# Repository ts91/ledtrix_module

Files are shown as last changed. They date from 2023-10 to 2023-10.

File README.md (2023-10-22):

# Ledtrix, a fully modular 16x16 LED matrix

Tileable and low profile (less than 1cm) for display applications. Can be used in an artsy clock. Each single LED is source/sink driven by a pair of transistors.

The transistors are controlled by shift-registers. There are 4 daisy-chained shift-registers with each 8 outputs giving the required 16 rows and 16 columns drive signals.

## Tileable
The outline of the unit is the same as 4 LED modules in a 2x2 configuration. This makes it possible to seamlessly tile the Ledtrix along any of its four edges.

Signals travel through the board from the left to the right indicated by the arrow and socket. The boards are soldered together by edge connectors. Soldering all of these gives a sturdy unit.

### Mounting holes
There are four mount holes on the back. It is impossible to reach these holes once the LED modules have been soldered onto the PCB. They can be used with press fit mount stages.

## Driving the Ledtrix
This can be tricky as the focus has been to make the PCB routing as simple as possible. Some thought must be put into it.
## Pictures
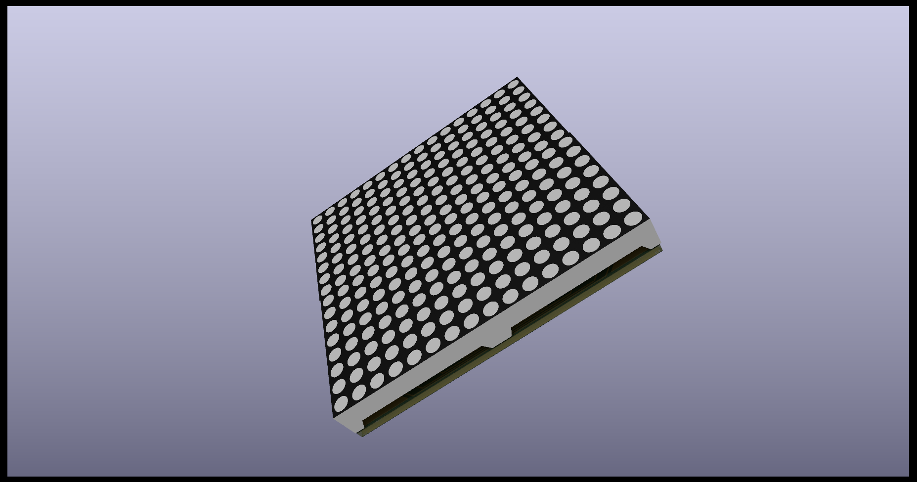
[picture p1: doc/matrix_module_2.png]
Ledtrix, front Front view - with 8x8 LEDs mounted

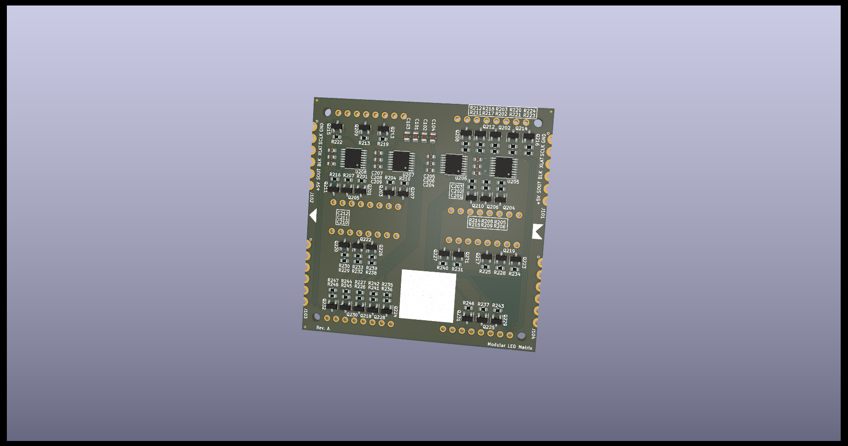
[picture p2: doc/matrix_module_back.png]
Ledtrix, back Back view - SMD component side

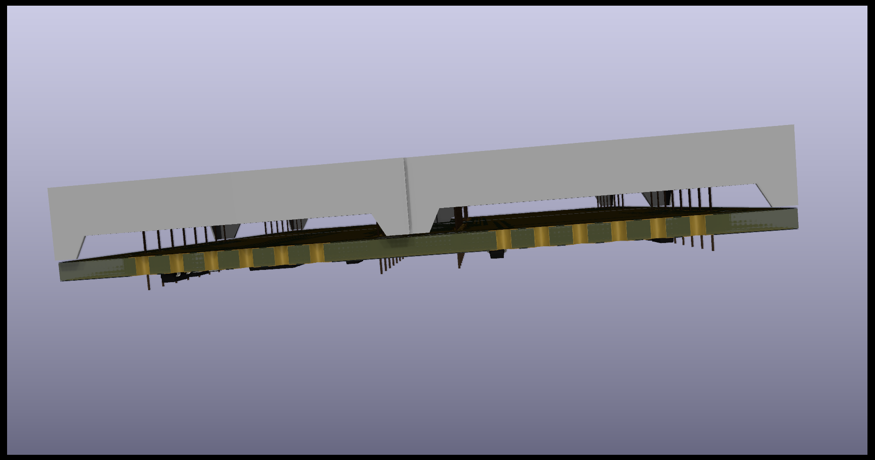
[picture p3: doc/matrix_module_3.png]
Ledtrix, side Side view - profile <1cm thickness

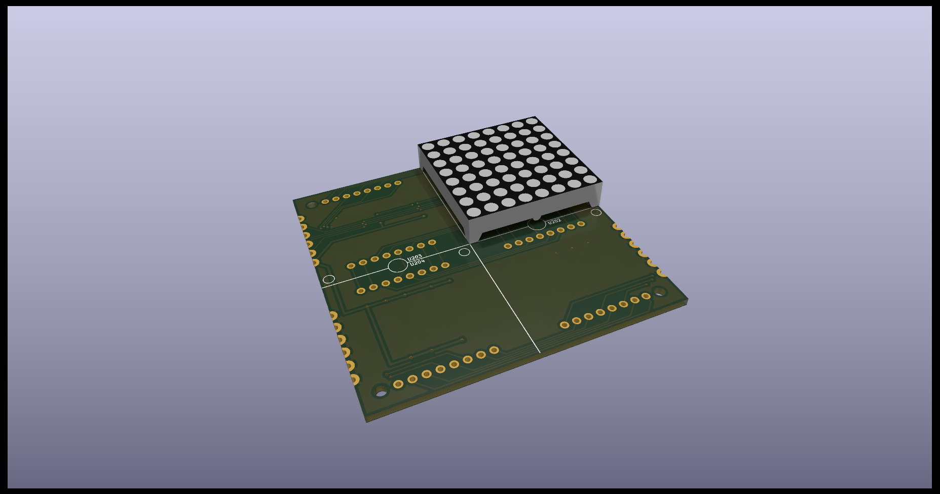
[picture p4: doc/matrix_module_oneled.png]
Ledtrix, front w. one LED Front view - one LED module mounted


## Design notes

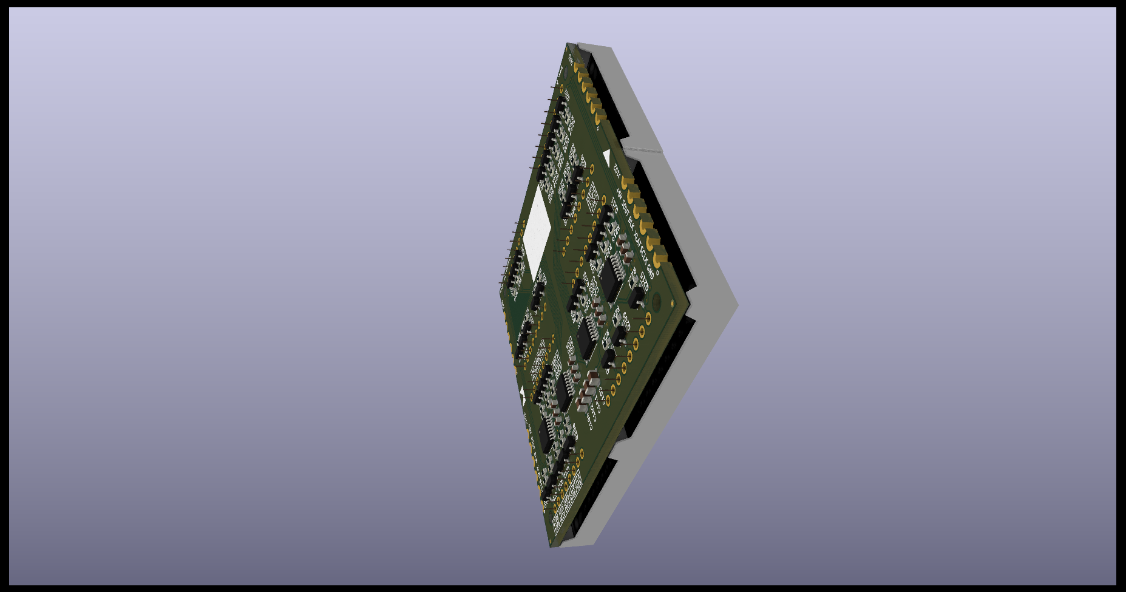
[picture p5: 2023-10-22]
doc/matrix_module_1.png

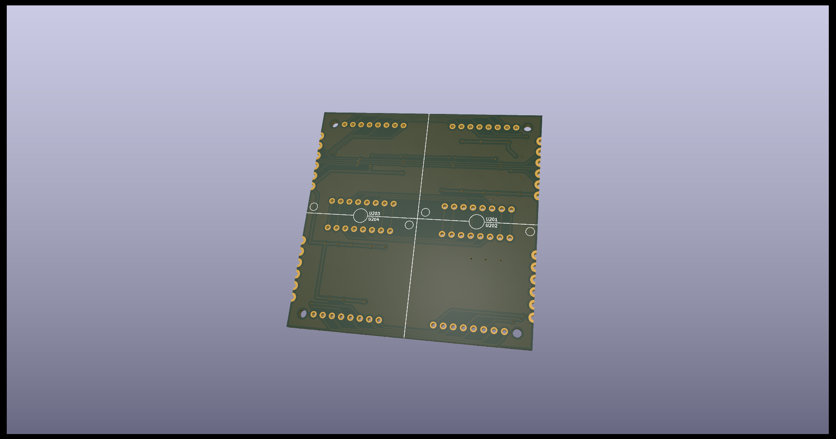
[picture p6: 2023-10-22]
doc/matrix_module_noleds.png

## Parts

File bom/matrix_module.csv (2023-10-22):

Comment | Designator | Footprint | LCSC
10u | C101,C102,C103,C104 | Capacitor_SMD:C_0805_2012Metric
100n | C201,C202,C203,C204,C205,C206,C207,C208,C209,C210,C211,C212 | Capacitor_SMD:C_0603_1608Metric
Fiducial | FID101,FID102,FID103 | Fiducials:Fiducial_0.5mm_Dia_1mm_Outer
MountingHole | H101,H102,H103,H104 | MountingHole:MountingHole_2.2mm_M2
Conn_01x06_Male | J101 | thms:CastellatedEdge_1x06P3.175mm_Vertical
Conn_01x06_Female | J102,J103,J104 | thms:CastellatedEdge_1x06P3.175mm_Vertical
BC807 | Q201,Q203,Q205,Q207,Q209,Q211,Q213,Q215,Q217,Q219,Q221,Q223,Q225,Q227,Q229,Q231 | Package_TO_SOT_SMD:SOT-23
BC817 | Q202,Q204,Q206,Q208,Q210,Q212,Q214,Q216,Q218,Q220,Q222,Q224,Q226,Q228,Q230,Q232 | Package_TO_SOT_SMD:SOT-23
1k | R201,R202,R204,R205,R207,R208,R210,R211,R213,R214,R216,R217,R219,R220,R222,R223,R225,R226,R228,R229,R231,R232,R234,R235,R237,R238,R240,R241,R243,R244,R246,R247 | Resistor_SMD:R_0603_1608Metric
500 | R203,R206,R209,R212,R215,R218,R221,R224,R227,R230,R233,R236,R239,R242,R245,R248 | Resistor_SMD:R_0603_1608Metric
1088BS | U201,U202,U203,U204 | thms:8x8_dotmatrix_1088_Pin_Header
74HC595 | U205,U206,U207,U208 | Package_SO:TSSOP-16_4.4x5mm_P0.65mm | C5948

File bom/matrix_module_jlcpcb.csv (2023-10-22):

Comment | Designator | Footprint | LCSC
10u | C101,C102,C103,C104 | 0805 | C440198
100n | C201,C202,C203,C204,C205,C206,C207,C208,C209,C210,C211,C212 | 0603 | C14663
BC807 | Q201,Q203,Q205,Q207,Q209,Q211,Q213,Q215,Q217,Q219,Q221,Q223,Q225,Q227,Q229,Q231 | SOT-23 | C2926191
BC817 | Q202,Q204,Q206,Q208,Q210,Q212,Q214,Q216,Q218,Q220,Q222,Q224,Q226,Q228,Q230,Q232 | SOT-23 | C2926190
1k | R201,R202,R204,R205,R207,R208,R210,R211,R213,R214,R216,R217,R219,R220,R222,R223,R225,R226,R228,R229,R231,R232,R234,R235,R237,R238,R240,R241,R243,R244,R246,R247 | 0603 | C21190
500 | R203,R206,R209,R212,R215,R218,R221,R224,R227,R230,R233,R236,R239,R242,R245,R248 | 0603 | C23179
74HC595 | U205,U206,U207,U208 | TSSOP-16_4.4x5mm_P0.65mm | C5948

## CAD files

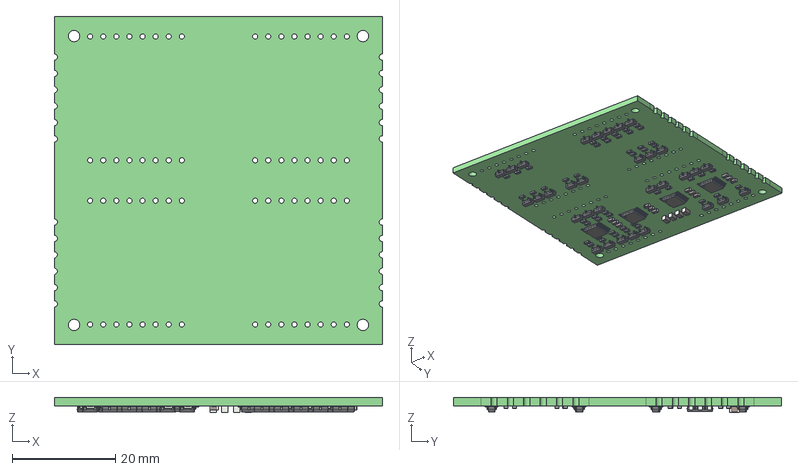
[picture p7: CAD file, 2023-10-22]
matrix_module.step
63.6 x 63.6 x 2.90 mm
matrix_module PCB

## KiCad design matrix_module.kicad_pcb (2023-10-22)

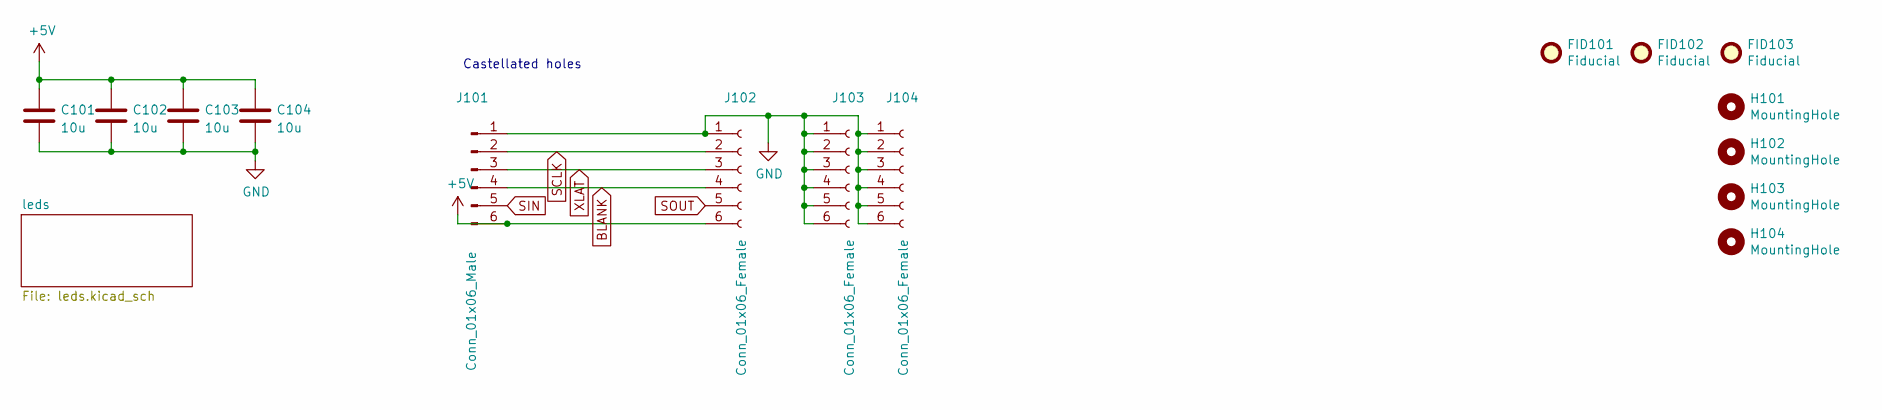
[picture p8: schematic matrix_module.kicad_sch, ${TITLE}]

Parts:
C101, C102, C103, C104: 10u; C_0805_2012Metric
FID101, FID102, FID103: Fiducial; Fiducial_0.5mm_Dia_1mm_Outer
H101, H102, H103, H104: MountingHole; MountingHole_2.2mm_M2
J101: Conn_01x06_Male; CastellatedEdge_1x06P3.175mm_Vertical
J102, J103, J104: Conn_01x06_Female; CastellatedEdge_1x06P3.175mm_Vertical

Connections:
+5V: C101.1, C102.1, C103.1, C104.1, J101.6, J102.6; also elsewhere on the board
BLANK: J101.4, J102.4; also elsewhere on the board
GND: C101.2, C102.2, C103.2, C104.2, J101.1, J102.1, J103.1, J103.2, J103.3, J103.4, J103.5, J103.6, J104.1, J104.2, J104.3, J104.4, J104.5, J104.6; also elsewhere on the board
SCLK: J101.2, J102.2; also elsewhere on the board
SIN: J101.5; also elsewhere on the board
SOUT: J102.5; also elsewhere on the board
XLAT: J101.3, J102.3; also elsewhere on the board

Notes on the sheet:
Castellated holes

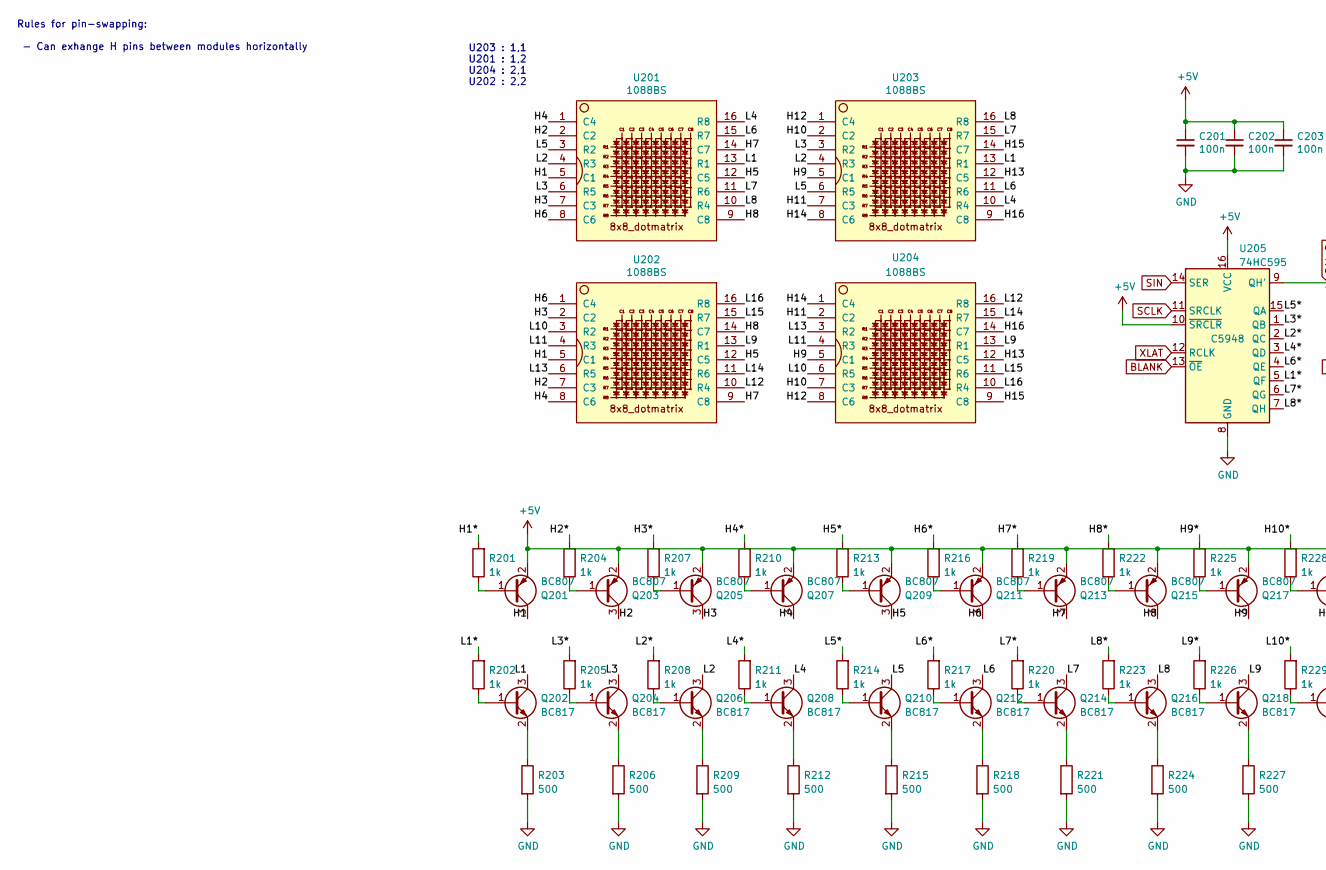
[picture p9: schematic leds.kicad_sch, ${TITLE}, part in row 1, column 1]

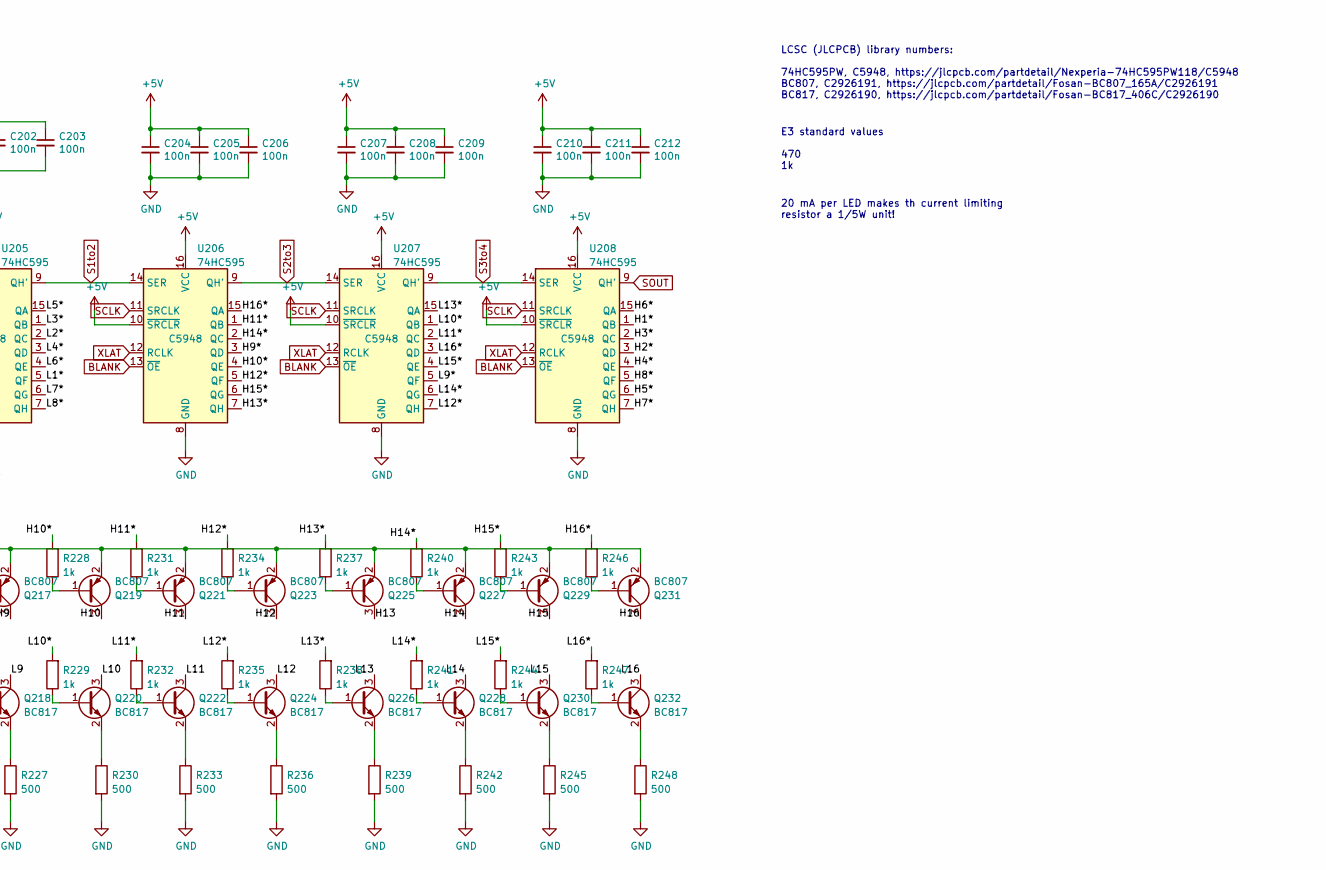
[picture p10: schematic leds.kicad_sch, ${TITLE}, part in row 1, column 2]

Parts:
C201, C202, C203, C204, C205, C206, C207, C208, C209, C210, C211, C212: 100n; C_0603_1608Metric
Q201, Q203, Q205, Q207, Q209, Q211, Q213, Q215, Q217, Q219, Q221, Q223, Q225, Q227, Q229, Q231: BC807; SOT-23
Q202, Q204, Q206, Q208, Q210, Q212, Q214, Q216, Q218, Q220, Q222, Q224, Q226, Q228, Q230, Q232: BC817; SOT-23
R201, R202, R204, R205, R207, R208, R210, R211, R213, R214, R216, R217, R219, R220, R222, R223, R225, R226, R228, R229, R231, R232, R234, R235, R237, R238, R240, R241, R243, R244, R246, R247: 1k; R_0603_1608Metric
R203, R206, R209, R212, R215, R218, R221, R224, R227, R230, R233, R236, R239, R242, R245, R248: 500; R_0603_1608Metric
U201, U202, U203, U204: 1088BS; 8x8_dotmatrix_1088
U205, U206, U207, U208: 74HC595; TSSOP-16_4.4x5mm_P0.65mm; LCSC C5948

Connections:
+5V: C201.1, C202.1, C203.1, C204.1, C205.1, C206.1, C207.1, C208.1, C209.1, C210.1, C211.1, C212.1, Q201.2 (E), Q203.2 (E), Q205.2 (E), Q207.2 (E), Q209.2 (E), Q211.2 (E), Q213.2 (E), Q215.2 (E), Q217.2 (E), Q219.2 (E), Q221.2 (E), Q223.2 (E), Q225.2 (E), Q227.2 (E), Q229.2 (E), Q231.2 (E), U205.10 (~SRCLR), U205.16 (VCC), U206.10 (~SRCLR), U206.16 (VCC), U207.10 (~SRCLR), U207.16 (VCC), U208.10 (~SRCLR), U208.16 (VCC); also elsewhere on the board
/leds/H1: Q201.3 (C), U201.5 (C1), U202.5 (C1)
/leds/H1*: R201.2, U208.1 (QB)
/leds/H2: Q203.3 (C), U201.2 (C2), U202.7 (C3)
/leds/H2*: R204.2, U208.3 (QD)
/leds/H3: Q205.3 (C), U201.7 (C3), U202.2 (C2)
/leds/H3*: R207.2, U208.2 (QC)
/leds/H4: Q207.3 (C), U201.1 (C4), U202.8 (C6)
/leds/H4*: R210.2, U208.4 (QE)
/leds/H5: Q209.3 (C), U201.12 (C5), U202.12 (C5)
/leds/H5*: R213.2, U208.6 (QG)
/leds/H6: Q211.3 (C), U201.8 (C6), U202.1 (C4)
/leds/H6*: R216.2, U208.15 (QA)
/leds/H7: Q213.3 (C), U201.14 (C7), U202.9 (C8)
/leds/H7*: R219.2, U208.7 (QH)
/leds/H8: Q215.3 (C), U201.9 (C8), U202.14 (C7)
/leds/H8*: R222.2, U208.5 (QF)
/leds/H9: Q217.3 (C), U203.5 (C1), U204.5 (C1)
/leds/H9*: R225.2, U206.3 (QD)
/leds/H10: Q219.3 (C), U203.2 (C2), U204.7 (C3)
/leds/H10*: R228.2, U206.4 (QE)
/leds/H11: Q221.3 (C), U203.7 (C3), U204.2 (C2)
/leds/H11*: R231.2, U206.1 (QB)
/leds/H12: Q223.3 (C), U203.1 (C4), U204.8 (C6)
/leds/H12*: R234.2, U206.5 (QF)
/leds/H13: Q225.3 (C), U203.12 (C5), U204.12 (C5)
/leds/H13*: R237.2, U206.7 (QH)
/leds/H14: Q227.3 (C), U203.8 (C6), U204.1 (C4)
/leds/H14*: R240.2, U206.2 (QC)
/leds/H15: Q229.3 (C), U203.14 (C7), U204.9 (C8)
/leds/H15*: R243.2, U206.6 (QG)
/leds/H16: Q231.3 (C), U203.9 (C8), U204.14 (C7)
/leds/H16*: R246.2, U206.15 (QA)
/leds/L1: Q202.3 (C), U201.13 (R1), U203.13 (R1)
/leds/L1*: R202.2, U205.5 (QF)
/leds/L2: Q206.3 (C), U201.4 (R3), U203.4 (R3)
/leds/L2*: R208.2, U205.2 (QC)
/leds/L3: Q204.3 (C), U201.6 (R5), U203.3 (R2)
/leds/L3*: R205.2, U205.1 (QB)
/leds/L4: Q208.3 (C), U201.16 (R8), U203.10 (R4)
/leds/L4*: R211.2, U205.3 (QD)
/leds/L5: Q210.3 (C), U201.3 (R2), U203.6 (R5)
/leds/L5*: R214.2, U205.15 (QA)
/leds/L6: Q212.3 (C), U201.15 (R7), U203.11 (R6)
/leds/L6*: R217.2, U205.4 (QE)
/leds/L7: Q214.3 (C), U201.11 (R6), U203.15 (R7)
/leds/L7*: R220.2, U205.6 (QG)
/leds/L8: Q216.3 (C), U201.10 (R4), U203.16 (R8)
/leds/L8*: R223.2, U205.7 (QH)
/leds/L9: Q218.3 (C), U202.13 (R1), U204.13 (R1)
/leds/L9*: R226.2, U207.5 (QF)
/leds/L10: Q220.3 (C), U202.3 (R2), U204.6 (R5)
/leds/L10*: R229.2, U207.1 (QB)
/leds/L11: Q222.3 (C), U202.4 (R3), U204.4 (R3)
/leds/L11*: R232.2, U207.2 (QC)
/leds/L12: Q224.3 (C), U202.10 (R4), U204.16 (R8)
/leds/L12*: R235.2, U207.7 (QH)
/leds/L13: Q226.3 (C), U202.6 (R5), U204.3 (R2)
/leds/L13*: R238.2, U207.15 (QA)
/leds/L14: Q228.3 (C), U202.11 (R6), U204.15 (R7)
/leds/L14*: R241.2, U207.6 (QG)
/leds/L15: Q230.3 (C), U202.15 (R7), U204.11 (R6)
/leds/L15*: R244.2, U207.4 (QE)
/leds/L16: Q232.3 (C), U202.16 (R8), U204.10 (R4)
/leds/L16*: R247.2, U207.3 (QD)
BLANK: U205.13 (~OE), U206.13 (~OE), U207.13 (~OE), U208.13 (~OE); also elsewhere on the board
GND: C201.2, C202.2, C203.2, C204.2, C205.2, C206.2, C207.2, C208.2, C209.2, C210.2, C211.2, C212.2, R203.2, R206.2, R209.2, R212.2, R215.2, R218.2, R221.2, R224.2, R227.2, R230.2, R233.2, R236.2, R239.2, R242.2, R245.2, R248.2, U205.8 (GND), U206.8 (GND), U207.8 (GND), U208.8 (GND); also elsewhere on the board
unnamed: Q201.1 (B), R201.1
unnamed: Q202.1 (B), R202.1
unnamed: Q202.2 (E), R203.1
unnamed: Q203.1 (B), R204.1
unnamed: Q204.1 (B), R205.1
unnamed: Q204.2 (E), R206.1
unnamed: Q205.1 (B), R207.1
unnamed: Q206.1 (B), R208.1
unnamed: Q206.2 (E), R209.1
unnamed: Q207.1 (B), R210.1
unnamed: Q208.1 (B), R211.1
unnamed: Q208.2 (E), R212.1
unnamed: Q209.1 (B), R213.1
unnamed: Q210.1 (B), R214.1
unnamed: Q210.2 (E), R215.1
unnamed: Q211.1 (B), R216.1
unnamed: Q212.1 (B), R217.1
unnamed: Q212.2 (E), R218.1
unnamed: Q213.1 (B), R219.1
unnamed: Q214.1 (B), R220.1
unnamed: Q214.2 (E), R221.1
unnamed: Q215.1 (B), R222.1
unnamed: Q216.1 (B), R223.1
unnamed: Q216.2 (E), R224.1
unnamed: Q217.1 (B), R225.1
unnamed: Q218.1 (B), R226.1
unnamed: Q218.2 (E), R227.1
unnamed: Q219.1 (B), R228.1
unnamed: Q220.1 (B), R229.1
unnamed: Q220.2 (E), R230.1
unnamed: Q221.1 (B), R231.1
unnamed: Q222.1 (B), R232.1
unnamed: Q222.2 (E), R233.1
unnamed: Q223.1 (B), R234.1
unnamed: Q224.1 (B), R235.1
unnamed: Q224.2 (E), R236.1
unnamed: Q225.1 (B), R237.1
unnamed: Q226.1 (B), R238.1
unnamed: Q226.2 (E), R239.1
unnamed: Q227.1 (B), R240.1
unnamed: Q228.1 (B), R241.1
unnamed: Q228.2 (E), R242.1
unnamed: Q229.1 (B), R243.1
unnamed: Q230.1 (B), R244.1
unnamed: Q230.2 (E), R245.1
unnamed: Q231.1 (B), R246.1
unnamed: Q232.1 (B), R247.1
unnamed: Q232.2 (E), R248.1
S1to2: U205.9 (QH'), U206.14 (SER)
S2to3: U206.9 (QH'), U207.14 (SER)
S3to4: U207.9 (QH'), U208.14 (SER)
SCLK: U205.11 (SRCLK), U206.11 (SRCLK), U207.11 (SRCLK), U208.11 (SRCLK); also elsewhere on the board
SIN: U205.14 (SER); also elsewhere on the board
SOUT: U208.9 (QH'); also elsewhere on the board
XLAT: U205.12 (RCLK), U206.12 (RCLK), U207.12 (RCLK), U208.12 (RCLK); also elsewhere on the board

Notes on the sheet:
E3 standard values 470 1k
U203 : 1,1 U201 : 1,2 U204 : 2,1 U202 : 2,2
20 mA per LED makes th current limiting resistor a 1/5W unit!
Rules for pin-swapping: - Can exhange H pins between modules horizontally
LCSC (JLCPCB) library numbers: 74HC595PW, C5948, https://jlcpcb.com/partdetail/Nexperia-74HC595PW118/C5948 BC807, C2926191, https://jlcpcb.com/partdetail/Fosan-BC807_165A/C2926191 BC817, C2926190, https://jlcpcb.com/partdetail/Fosan-BC817_406C/C2926190

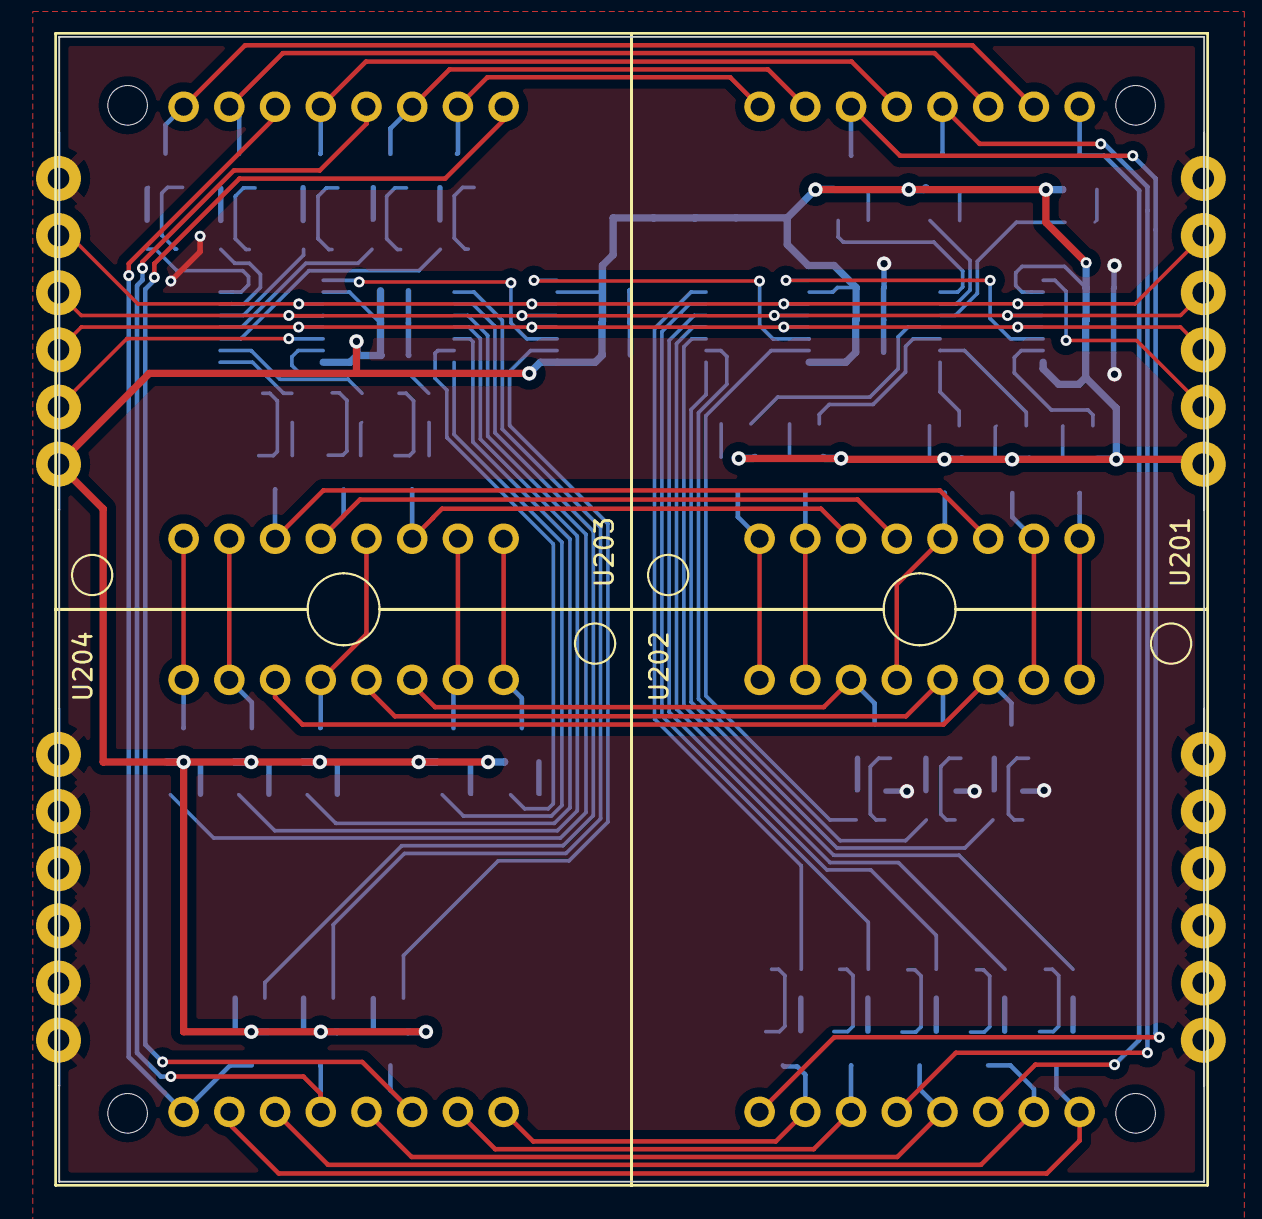
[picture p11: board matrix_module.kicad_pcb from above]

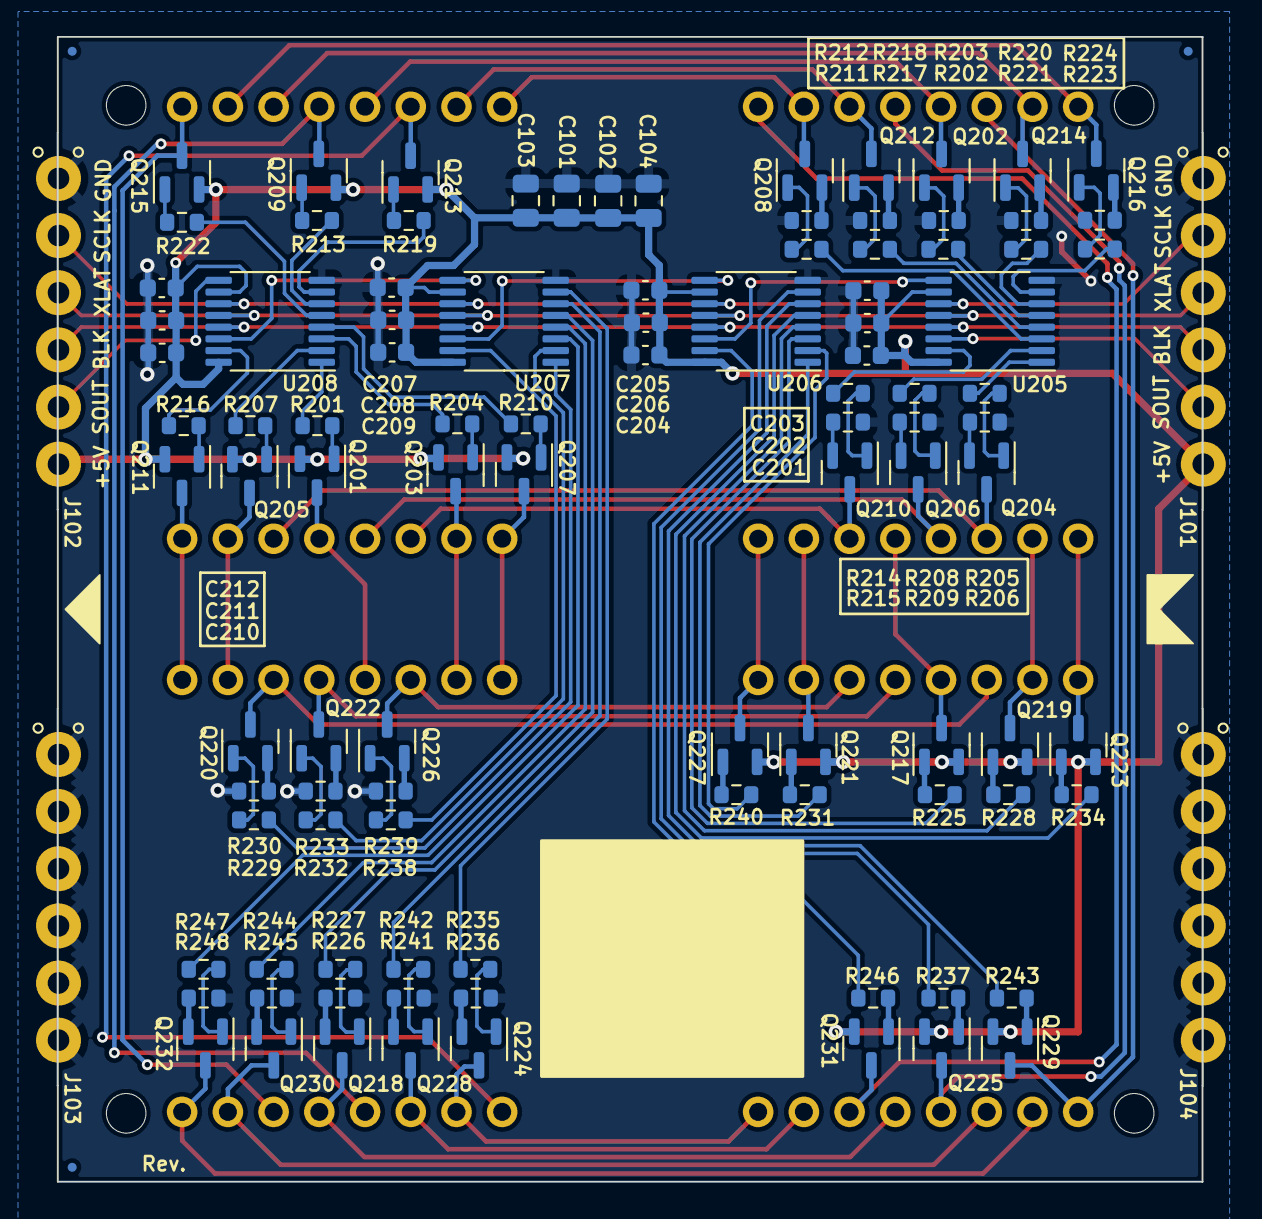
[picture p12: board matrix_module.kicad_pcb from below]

Board: 2 copper layers, 63.6 x 63.6 mm, 115 parts (107 on the bottom side), 122 nets.
